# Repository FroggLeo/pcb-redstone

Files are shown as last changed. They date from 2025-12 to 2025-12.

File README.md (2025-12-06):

# PCB Redstone
Minecraft redstone but with real PCB tiles, connecting magnetically and functions just like the game!

Picture of the redstone dust

## Features:
- RP2040 microcontroller
- 40*40mm compact design 
- Dual 4 pin magentic pogo pins to connect on any side (2 pins per channel)
- Lots of toggleable LEDs to match block functions!
- Simulate Java or Bedrock redstone mechanics
- Program with 2.54mm holes using SWD
- Communicate with 2 GPIO inputs/outputs
- Inject 12v sources to any tiles and power all the blocks

## Current blocks:
### Redstone Dust
pcb of the redstone dust
schematic of redstone dust
### Redstone Block
pcb of the redstone block
### Redstone Comparator
pcb of the redstone lamp
### Redstone Lamp & Copper Lamp
pcb of the redstone repeater
### Redstone Repeater
pcb of the redstone comparator

## Firmware:
[Firmware for the PCB redstone can be found here!](https://github.com/Hashikono/recom-simulation)

## Honorable mentions:
- KiCad
- Mouser library importer
- Little bits (initial inspiration!)
- Kaylee [@kaylz-d](https://github.com/kaylz-d)
- Hack Club Blueprint

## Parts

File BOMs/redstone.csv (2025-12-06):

Reference | Qty | Value | Footprint | Datasheet
C1 | 1 | 10uF | SamacSys_Parts:CAPC1005X70N | http://www.murata.com/~/media/webrenewal/support/library/catalog/products/capacitor/mlcc/c02e.pdf
C2,C3,C6,C10 | 4 | 0.1uF | SamacSys_Parts:CAPC2012X140N | https://content.kemet.com/datasheets/KEM_C1014_X7R_FE-CAP_SMD.pdf
C4,C5 | 2 | 22uF | SamacSys_Parts:GRM18x | https://search.murata.co.jp/Ceramy/image/img/A01X/G101/ENG/GRM188C81A226ME01-01A.pdf
C7,C9,C11 | 3 | 1uF | SamacSys_Parts:CAPC0603X33N | https://search.murata.co.jp/Ceramy/image/img/A01X/G101/ENG/GRM033D70E105ME15-01A.pdf
D1,D2,D3,D4,D5,D6,D7,D8,D9,D10,D11,D12,D13,D14,D15,D16 | 16 | LED | SamacSys_Parts:LEDC1608X115N | ~
D17,D18,D20,D21 | 4 | VGSOT03C-HG3-08 | SamacSys_Parts:SOT95P248X115-3N | https://www.vishay.com/docs/86325/vgsot03c-vgsot36c.pdf
D19 | 1 | SMBJ15A | SamacSys_Parts:DIOM5436X244N | http://www.vishay.com/docs/88392/smbj.pdf
J1,J2,J3,J4,J5,J6,J7,J8 | 8 | 1x4_Pogo | Connector_PinSocket_2.54mm:PinSocket_1x04_P2.54mm_Vertical | ~
J9 | 1 | 2.54mm_ProgrammingPin | Connector_PinSocket_2.54mm:PinSocket_1x04_P2.54mm_Vertical | ~
L1 | 1 | 2.2uH | SamacSys_Parts:LCENA2016MKT2R2M0NK | ~
Q1,Q2,Q3,Q4 | 4 | MMBT3904 | Package_TO_SOT_SMD:SOT-23 | https://www.onsemi.com/pdf/datasheet/pzt3904-d.pdf
R1,R2,R3,R4,R5,R6,R7,R8,R9,R10,R11,R12,R13,R14,R15,R16 | 16 | 200 | SamacSys_Parts:CRCW1210200RJNEAIF | ~
R17 | 1 | 100k | SamacSys_Parts:TNPW0805100KFHEA | ~
R18,R19,R20,R21 | 4 | 1k | SamacSys_Parts:ERJ-UP6D1001V | ~
SW1 | 1 | SW_Push_Open | Button_Switch_THT:SW_TH_Tactile_Omron_B3F-100x | ~
SW2 | 1 | SW_DIP_x01 | SamacSys_Parts:416131160801 | ~
U1 | 1 | RP2040 | Package_DFN_QFN:QFN-56-1EP_7x7mm_P0.4mm_EP3.2x3.2mm | https://datasheets.raspberrypi.com/rp2040/rp2040-datasheet.pdf
U2 | 1 | RBT05W24S05 | SamacSys_Parts:RBT10W24S05_XPP_XPR | RBT05W24S05
U3 | 1 | TPS62162DSG | Package_SON:WSON-8-1EP_2x2mm_P0.5mm_EP0.9x1.6mm_ThermalVias | http://www.ti.com/lit/ds/symlink/tps62160.pdf
U5 | 1 | W25Q16JVSS | Package_SO:SOIC-8_5.3x5.3mm_P1.27mm | https://www.winbond.com/hq/support/documentation/levelOne.jsp?__locale=en&DocNo=DA00-W25Q16JV.1

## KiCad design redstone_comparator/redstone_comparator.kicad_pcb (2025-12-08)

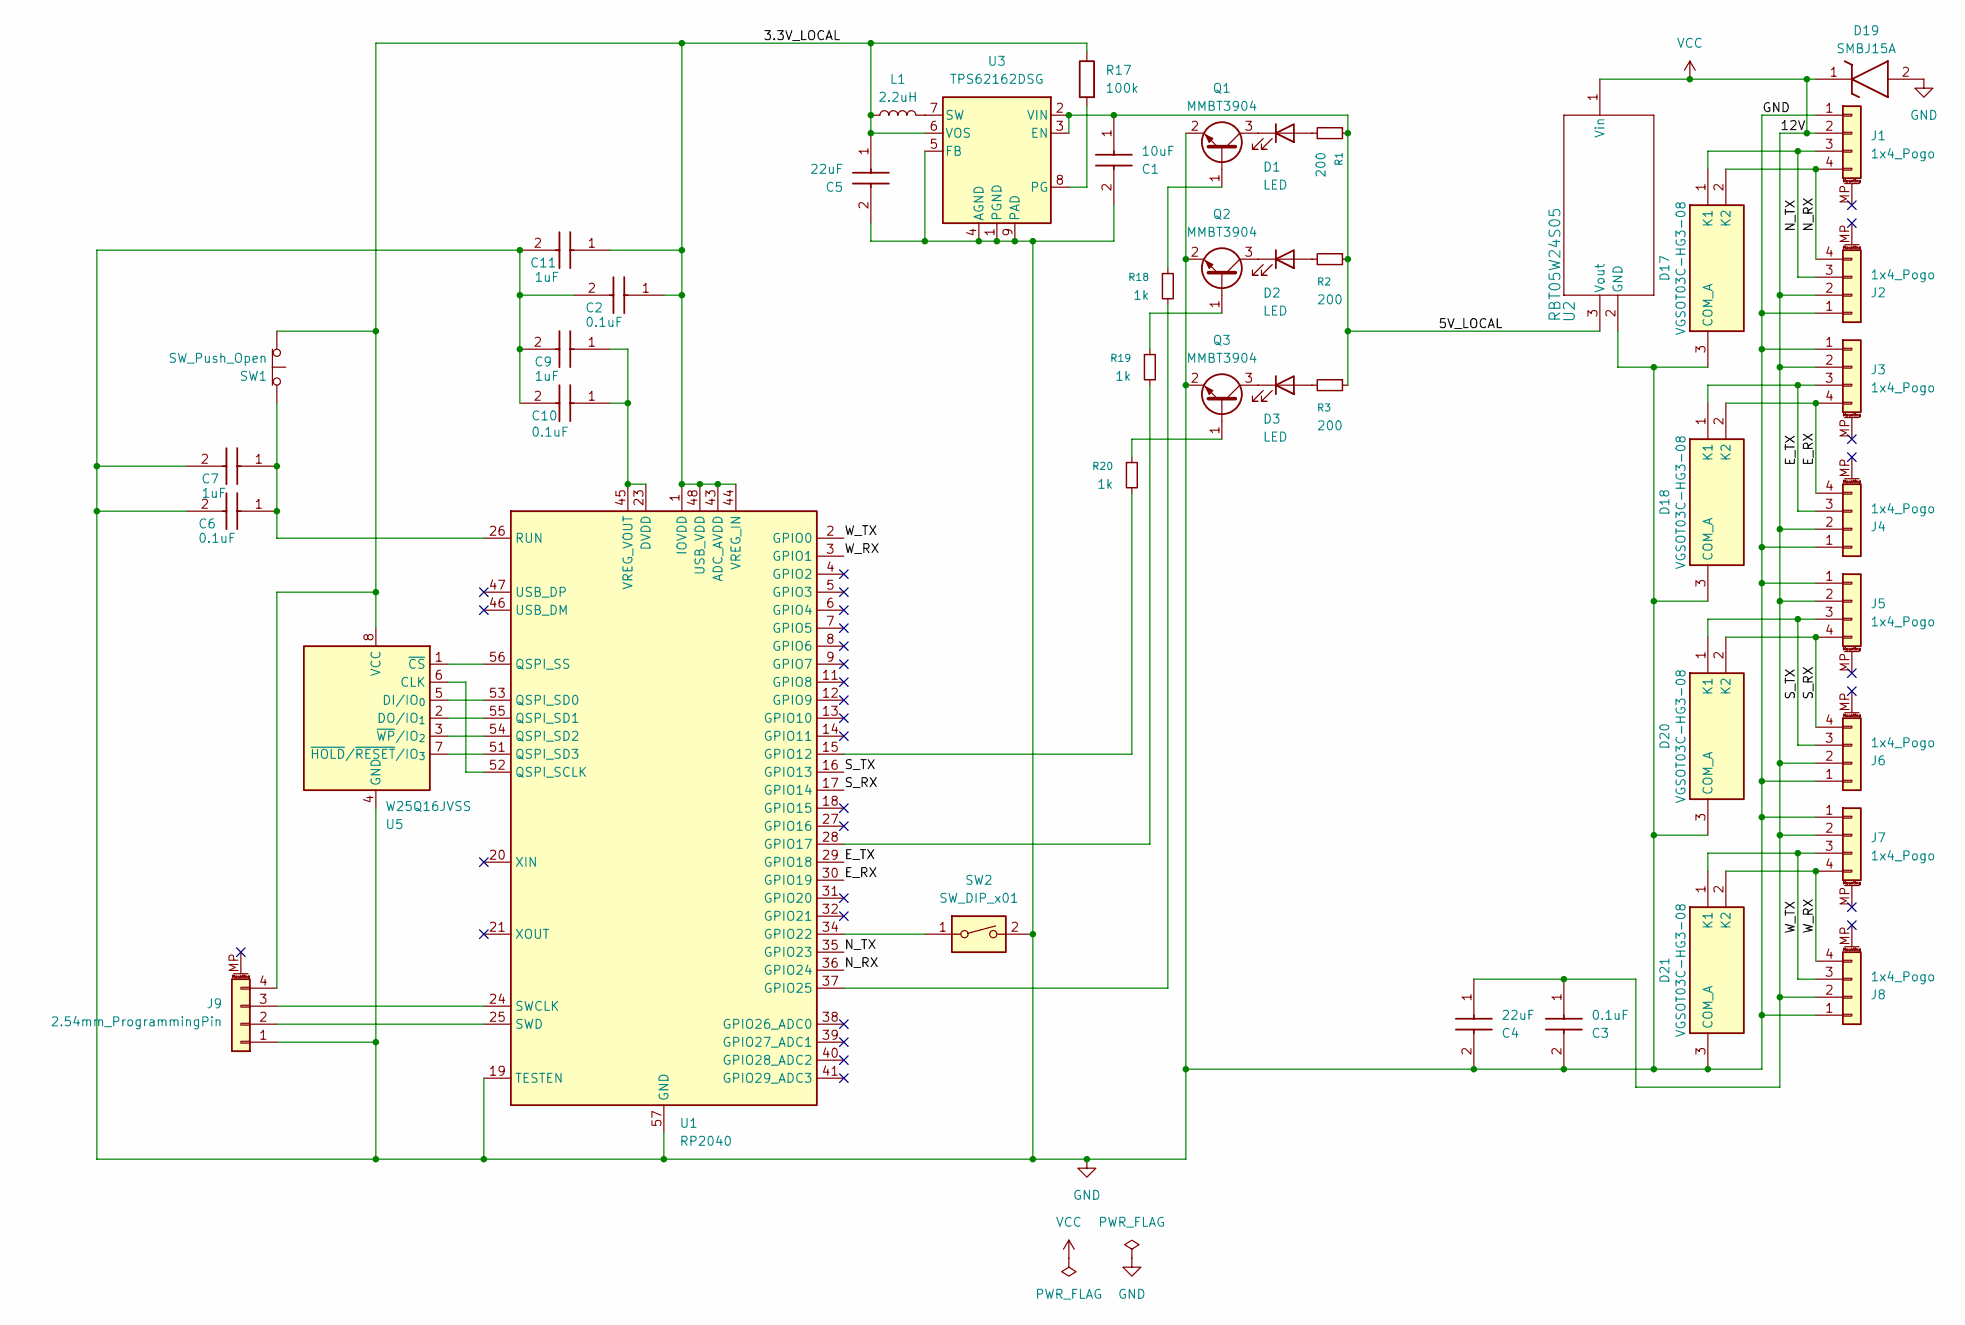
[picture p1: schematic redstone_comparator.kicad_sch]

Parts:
C1: 10uF; CAPC1005X70N; Manufacturer_Part_Number GRM155R60J106ME18D
C2, C3, C6, C10: 0.1uF; CAPC2012X140N; Manufacturer_Part_Number C0805F104K1RACAUTO
C4, C5: 22uF; GRM18x; Manufacturer_Part_Number GRM188C81A226ME01D
C7, C9, C11: 1uF; CAPC0603X33N; Manufacturer_Part_Number GRM033D70E105ME15D; Mouser Part Number 81-GRM033D70E105ME5D
D1, D2, D3: LED; LED_D3.0mm
D17, D18, D20, D21: VGSOT03C-HG3-08; SOT95P248X115-3N; Manufacturer_Part_Number VGSOT03C-HG3-08
D19: SMBJ15A; DIOM5436X244N; Manufacturer_Part_Number SMBJ15A; Mouser Part Number 78-SMBJ15A
J1, J2, J3, J4, J5, J6, J7, J8: 1x4_Pogo; PinSocket_1x04_P2.54mm_Vertical
J9: 2.54mm_ProgrammingPin; PinSocket_1x04_P2.54mm_Vertical
L1: 2.2uH; LCENA2016MKT2R2M0NK
Q1, Q2, Q3: MMBT3904; SOT-23
R1, R2, R3: 200; CRCW1210200RJNEAIF
R17: 100k; TNPW0805100KFHEA
R18, R19, R20: 1k; ERJ-UP6D1001V
SW1: SW_Push_Open; SW_TH_Tactile_Omron_B3F-100x
SW2: SW_DIP_x01; 416131160801
U1: RP2040; QFN-56-1EP_7x7mm_P0.4mm_EP3.2x3.2mm
U2: RBT05W24S05; RBT10W24S05_XPP_XPR
U3: TPS62162DSG; WSON-8-1EP_2x2mm_P0.5mm_EP0.9x1.6mm_ThermalVias
U5: W25Q16JVSS; SOIC-8_5.3x5.3mm_P1.27mm

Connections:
/3.3V_LOCAL: C2.1, C5.1, C11.1, J9.4, L1.1, R17.1, SW1.1 (A), U1.1 (IOVDD), U1.10 (IOVDD), U1.22 (IOVDD), U1.33 (IOVDD), U1.42 (IOVDD), U1.43 (ADC_AVDD), U1.44 (VREG_IN), U1.48 (USB_VDD), U1.49 (IOVDD), U3.6 (VOS), U5.8 (VCC); also elsewhere on the board
/5V_LOCAL: C1.1, R1.1, R2.1, R3.1, U2.3 (Vout), U3.2 (VIN), U3.3 (EN)
/E_RX: D18.2 (K2), J3.4, J4.4, U1.30 (GPIO19)
/E_TX: D18.1 (K1), J3.3, J4.3, U1.29 (GPIO18)
/N_RX: D17.2 (K2), J1.4, J2.4, U1.36 (GPIO24)
/N_TX: D17.1 (K1), J1.3, J2.3, U1.35 (GPIO23)
/S_RX: D20.2 (K2), J5.4, J6.4, U1.17 (GPIO14)
/S_TX: D20.1 (K1), J5.3, J6.3, U1.16 (GPIO13)
/W_RX: D21.2 (K2), J7.4, J8.4, U1.3 (GPIO1)
/W_TX: D21.1 (K1), J7.3, J8.3, U1.2 (GPIO0)
GND: C1.2, C2.2, C3.2, C4.2, C5.2, C6.2, C7.2, C9.2, C10.2, C11.2, D17.3 (COM_A), D18.3 (COM_A), D19.2 (A), D20.3 (COM_A), D21.3 (COM_A), J1.1, J2.1, J3.1, J4.1, J5.1, J6.1, J7.1, J8.1, J9.1, Q1.2 (E), Q2.2 (E), Q3.2 (E), SW2.2, U1.19 (TESTEN), U1.57 (GND), U2.2 (GND), U3.1 (PGND), U3.4 (AGND), U3.5 (FB), U3.9 (PAD), U5.4 (GND); also elsewhere on the board
unnamed: D1.2 (A), R1.2
unnamed: D1.1 (K), Q1.3 (C)
unnamed: D2.2 (A), R2.2
unnamed: D2.1 (K), Q2.3 (C)
unnamed: D3.2 (A), R3.2
unnamed: D3.1 (K), Q3.3 (C)
unnamed: J9.2, U1.25 (SWD)
unnamed: J9.3, U1.24 (SWCLK)
unnamed: Q1.1 (B), R18.1
unnamed: Q2.1 (B), R19.1
unnamed: Q3.1 (B), R20.1
unnamed: C6.1, C7.1, SW1.2 (B), U1.26 (RUN)
unnamed: R20.2, U1.15 (GPIO12)
unnamed: R19.2, U1.28 (GPIO17)
unnamed: SW2.1, U1.34 (GPIO22)
unnamed: R18.2, U1.37 (GPIO25)
unnamed: U1.52 (QSPI_SCLK), U5.6 (CLK)
unnamed: U1.53 (QSPI_SD0), U5.5 (DI/IO_{0})
unnamed: U1.55 (QSPI_SD1), U5.2 (DO/IO_{1})
unnamed: U1.54 (QSPI_SD2), U5.3 (~WP/IO_{2})
unnamed: U1.51 (QSPI_SD3), U5.7 (~HOLD/~RESET/IO_{3})
unnamed: U1.56 (QSPI_SS), U5.1 (~CS)
unnamed 33: C9.1, C10.1, U1.23 (DVDD), U1.45 (VREG_VOUT), U1.50 (DVDD); also elsewhere on the board
unnamed: R17.2, U3.8 (PG)
unnamed: L1.2, U3.7 (SW)
VCC: C3.1, C4.1, D19.1 (K), J1.2, J2.2, J3.2, J4.2, J5.2, J6.2, J7.2, J8.2, U2.1 (Vin)

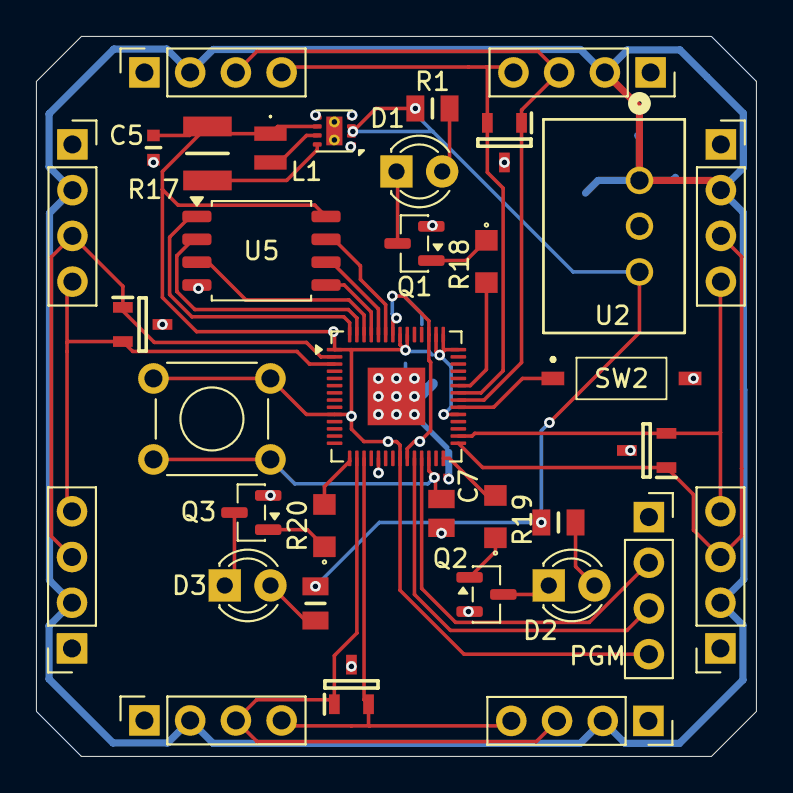
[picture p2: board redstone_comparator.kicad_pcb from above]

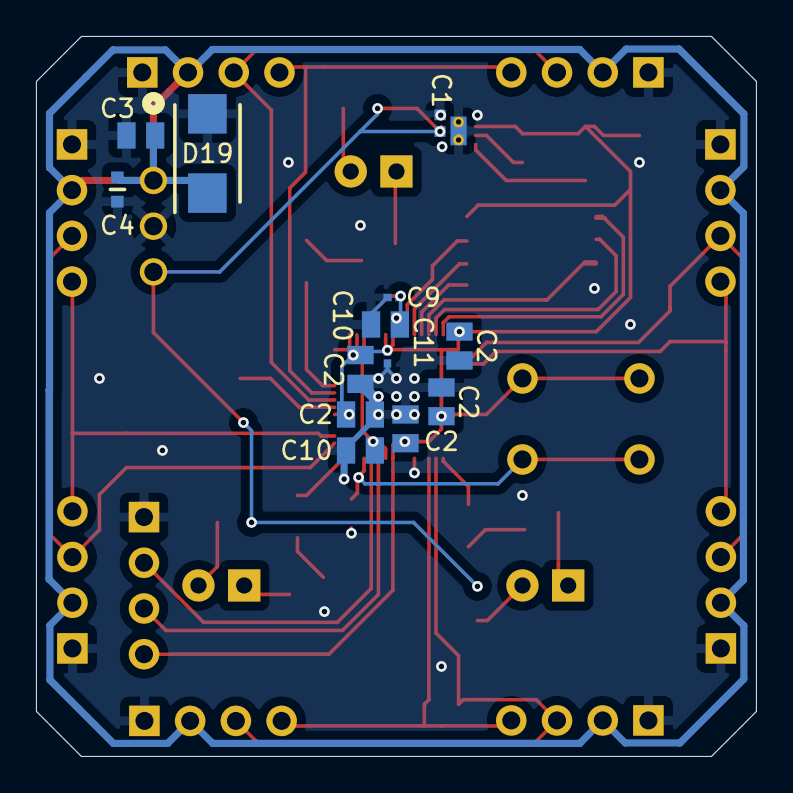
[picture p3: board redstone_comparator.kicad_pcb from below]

Board: 2 copper layers, 40.0 x 40.0 mm, 49 parts (13 on the bottom side), 37 nets.

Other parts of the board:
C2#2, C2#3, C2#4, C2#5, C10#2: 0.1uF; CAPC2012X140N

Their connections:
/3.3V_LOCAL: C2#2.1, C2#3.1, C2#4.1, C2#5.1; also elsewhere on the board
GND: C2#2.2, C2#3.2, C2#4.2, C2#5.2, C10#2.2; also elsewhere on the board
unnamed 33: C10#2.1; also elsewhere on the board

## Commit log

2025-11-06 add redstone dust files
    [redstone.kicad_pcb, redstone.kicad_sch]
2025-11-06 add more leds
    [redstone.kicad_sch]
2025-11-06 add tx rx wiring, add flash memory
    [redstone.kicad_sch]
2025-11-06 connect flash memory
    [redstone.kicad_sch]
2025-11-07 add gitignore entries for kicad
    [redstone.kicad_sch]
2025-11-07 add resistors with proper values
    [redstone.kicad_sch]
2025-11-07 add tvs diode and reorganize wiring
    [redstone.kicad_sch]
2025-11-07 add tps diodes for rx tx
    [redstone.kicad_sch]
2025-11-07 add decoupling capacitors
    [redstone.kicad_sch]
2025-11-07 add programming pins
    [redstone.kicad_sch]
2025-11-07 add no connect flags to unconnected pins
    [redstone.kicad_sch]
2025-11-07 run erc and fix some errors
    [redstone.kicad_sch]
2025-11-10 add decoupling capacitors for rp2040
    [redstone.kicad_sch]
2025-11-10 add some symbol footprints
    [redstone.kicad_sch]
2025-11-10 add footprint for pogo pins
    [redstone.kicad_sch]
2025-11-10 switch GND and VCC pins to match pcb footprint
    [redstone.kicad_pcb, redstone.kicad_sch]
2025-11-11 add basic pcb layout, fix disconnected ground net
    [redstone.kicad_pcb, redstone.kicad_sch]
2025-11-13 remove some unecessary capacitors
    [redstone.kicad_pcb, redstone.kicad_sch]
2025-11-13 add very bad traces, most likely will redo pcb layout
    [redstone.kicad_pcb]
2025-11-13 snapshot before removing all traces and restarting layout
    [redstone.kicad_pcb]
2025-11-13 remove all traces to restart layout
    [redstone.kicad_pcb]
2025-11-13 redoing pcb layout with new approach
    [redstone.kicad_pcb, redstone.kicad_sch]
2025-11-13 move pogo pin footprints over to new layout
    [redstone.kicad_pcb]
2025-11-13 connect more traces, progress is well
    [redstone.kicad_pcb, redstone.kicad_sch]
2025-11-13 add more traces, almost done
    [redstone.kicad_pcb, redstone.kicad_sch]
2025-11-14 add remaining tracks except ground
    [redstone.kicad_pcb]
2025-11-14 move pins closer to the corners, create ground plane fill on bottom
    [redstone.kicad_pcb, redstone.kicad_sch]
2025-11-14 reasolve all drc check errors, todo resolve warnings
    [redstone.kicad_pcb]
2025-11-14 fix front side silkscreens
    [redstone.kicad_pcb]
2025-11-16 change programming pin 4 to 3.3v
    [redstone.kicad_pcb, redstone.kicad_sch]
2025-11-17 fix all silkscreen drc errors
    [redstone.kicad_pcb]
2025-11-17 finalize redstone dust
    [redstone.kicad_pcb]
2025-11-17 duplicate redstone dust file and modify to fit redstone block
    [redstone_block.kicad_pcb, redstone_block.kicad_sch]
2025-11-18 finalize redstone block and duplicate redstone dust to create lamp
    [redstone_block.kicad_pcb, redstone_lamp.kicad_pcb, redstone_lamp.kicad_sch]
2025-11-18 remove all unecessary components in schematic
    [redstone_lamp.kicad_pcb, redstone_lamp.kicad_sch]
2025-11-18 finalize redstone lamp design
    [redstone_lamp.kicad_pcb, redstone_lamp.kicad_sch]
2025-11-18 clean up and organize redstone dust schematic
    [redstone.kicad_sch]
2025-11-18 remove unecessary silkscreen markings on redstone block
    [redstone_block.kicad_pcb]
2025-11-18 add dip switch to schematic, todo update pcb design
    [redstone.kicad_pcb, redstone.kicad_sch, redstone_block.kicad_pcb]
2025-11-19 remove dip switch, cannot find one that fits in board space
    [redstone.kicad_pcb, redstone.kicad_sch]
2025-11-19 duplicate redstone lamp project for redstone repeator
    [redstone_repeater.kicad_pcb, redstone_repeater.kicad_sch]
2025-11-19 add 4 way switch for repeater
    [redstone_repeater.kicad_sch]
2025-11-19 switch redstone dust transistor to a much smaller one, todo switch transistors on other tiles as well
    [redstone.kicad_pcb, redstone.kicad_sch]
2025-11-19 switch redstone lamp transistor to mmbt3904
    [redstone_lamp.kicad_pcb, redstone_lamp.kicad_sch]
2025-11-19 move reset buttom and add dip switch
    [redstone.kicad_pcb, redstone.kicad_sch]
2025-11-20 add four individually controlled leds for repeater, small adjustments for redstone dust
    [redstone.kicad_pcb, redstone_repeater.kicad_pcb, redstone_repeater.kicad_sch]
2025-11-21 reorganize pcb layout for redstone repeater
    [redstone_repeater.kicad_pcb]
2025-11-28 finalize schematic and finish layout of pcb
    [redstone_repeater.kicad_pcb, redstone_repeater.kicad_sch]
2025-11-28 finish wiring layout
    [redstone_repeater.kicad_pcb, redstone_repeater.kicad_sch]
2025-11-28 run drc, fix silkscreen, fix drc errors
    [redstone_repeater.kicad_pcb]
2025-11-29 duplicate redstone dust for comparator
    [redstone_comparator.kicad_pcb, redstone_comparator.kicad_sch]
2025-11-29 finalize initial comparator design
    [redstone_comparator.kicad_sch]
2025-11-29 finish routing all connections, todo align components and make it symmetric
    [redstone_comparator.kicad_pcb, redstone_comparator.kicad_sch]
2025-12-06 include csv for BOM
2025-12-06 add BOMs for all blocks
    [redstone.csv, redstone_block.csv, redstone_comparator.csv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]
2025-12-08 generate gerber files for all blocks
    [redstone-B_Cu.gbr, redstone-B_Mask.gbr, redstone-B_Paste.gbr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]
2025-12-08 organize all gerber files
    [redstone-B_Cu.gbr, redstone-B_Mask.gbr, redstone-B_Paste.gbr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]
